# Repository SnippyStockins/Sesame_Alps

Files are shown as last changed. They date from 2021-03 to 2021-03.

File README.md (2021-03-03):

# Sesame

[][cc-by-nc-sa]

### Alice like ergo keyboard using only THT parts



### Partslist
 |Count|Part|
 |-|-|
 |1|ATmega32A 40 pin DIP (32L works too)|
 |1|40 pin DIP socket (optional but highly recommended)|
 |1|USB4085-GF-A USB Type-C socket|
 |1|500 mA polyfuse|
 |2|6mm momentary push buttons|
 |1|16 MHz quartz crystal|
 |1|4.7 uF electrolytic capacitor|
 |2|100 nF ceramic disk capacitor|
 |2|22 pF ceramic disk capacitor|
 |1|10 kΩ resistor|
 |2|68 Ω resistor|
 |1|1.5 kΩ resistor|
 |2|5.1 kΩ resistor|
 |2|3.6 V zener diode (DO-35 BZX55C3V6)|
 |66|universal switching diode (DO-35 1N4148)|




This work is licensed under a
[Creative Commons Attribution-NonCommercial-ShareAlike 4.0 International License][cc-by-nc-sa].

[][cc-by-nc-sa]

[cc-by-nc-sa]: http://creativecommons.org/licenses/by-nc-sa/4.0/
[cc-by-nc-sa-image]: https://licensebuttons.net/l/by-nc-sa/4.0/88x31.png
[cc-by-nc-sa-shield]: https://img.shields.io/badge/License-CC%20BY--NC--SA%204.0-lightgrey.svg

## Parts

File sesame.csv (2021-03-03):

Id | Designator | Package | Quantity | Designation | Supplier and ref
1 | MX69,MX8,MX1,MX47,MX23,MX5,MX24,MX28,MX16,MX32,MX68,MX59,MX58,MX57,MX56,MX55,MX54,MX53,MX52,MX51,MX50,MX49,MX45,MX44,MX43,MX42,MX41,MX40,MX39,MX38,MX37,MX36,MX35,MX33,MX30,MX29,MX27,MX26,MX25,MX22,MX21,MX20,MX19,MX17,MX14,MX13,MX12,MX11,MX10,MX9,MX7,MX6,MX4,MX3,MX2,MX70,MX61 | MX-1U-NoLED | 57 | MX-NoLED
2 | U1 | DIP-40_W15.24mm | 1 | ATmega32A-PU
3 | MX60,MX34 | MX-1.75U-NoLED | 2 | MX-NoLED
4 | USB1 | USB_C_Receptacle_GCT_USB4085 | 1 | USB_C_Receptacle_USB2.0
5 | R6 | R_Axial_DIN0204_L3.6mm_D1.6mm_P7.62mm_Horizontal | 1 | 10k
6 | R4,R5 | R_Axial_DIN0204_L3.6mm_D1.6mm_P7.62mm_Horizontal | 2 | 75R
7 | R3,R2 | R_Axial_DIN0204_L3.6mm_D1.6mm_P7.62mm_Horizontal | 2 | 5.1K
8 | R1 | R_Axial_DIN0204_L3.6mm_D1.6mm_P7.62mm_Horizontal | 1 | 1.5K
9 | C5,C4 | C_Disc_D3.0mm_W1.6mm_P2.50mm | 2 | 22p
10 | C3,C2 | C_Disc_D4.3mm_W1.9mm_P5.00mm | 2 | 0.1u
11 | MX18,MX31 | MX-1.5U-NoLED | 2 | MX-NoLED
12 | MX15 | MX-2U-NoLED | 1 | MX-NoLED
13 | MX46,MX48 | MX-2.25U-NoLED | 2 | MX-NoLED
14 | MX62,MX63,MX65,MX67 | MX-1.25U-NoLED | 4 | MX-NoLED
15 | MX64 | MX-2U-ReversedStabilizers-NoLED | 1 | MX-NoLED
16 | MX66 | MX-2.75U-ReversedStabilizers-NoLED | 1 | MX-NoLED
17 | C1 | CP_Radial_D4.0mm_P1.50mm | 1 | 4.7u
18 | REF**,REF**,REF**,REF**,REF**,REF**,REF** | screw_hole | 7 | screw_hole
19 | AVR1 | PinHeader_1x06_P2.54mm_Vertical | 1 | Conn_01x06
20 | D60,D68,D67,D66,D65,D64,D63,D62,D61,D59,D58,D57,D56,D55,D54,D53,D52,D51,D50,D49,D48,D47,D45,D44,D43,D42,D41,D40,D39,D38,D37,D36,D35,D34,D33,D32,D31,D30,D29,D28,D27,D26,D25,D24,D23,D22,D21,D20,D19,D18,D15,D46,D14,D13,D12,D11,D10,D9,D8,D7,D6,D5,D4,D3,D2,D1,D16,D17,D69,D70 | D_DO-35_SOD27_P7.62mm_Horizontal | 70 | D_Small
21 | XTAL1 | Crystal_HC49-4H_Vertical | 1 | Crystal
22 | Reset1 | SW_PUSH_6mm | 1 | Reset
23 | F1 | Fuse_Littelfuse_395Series | 1 | 500mA
24 | Boot1 | SW_PUSH_6mm | 1 | Boot
25 | D71,D72 | D_DO-35_SOD27_P7.62mm_Horizontal | 2 | 3.6V

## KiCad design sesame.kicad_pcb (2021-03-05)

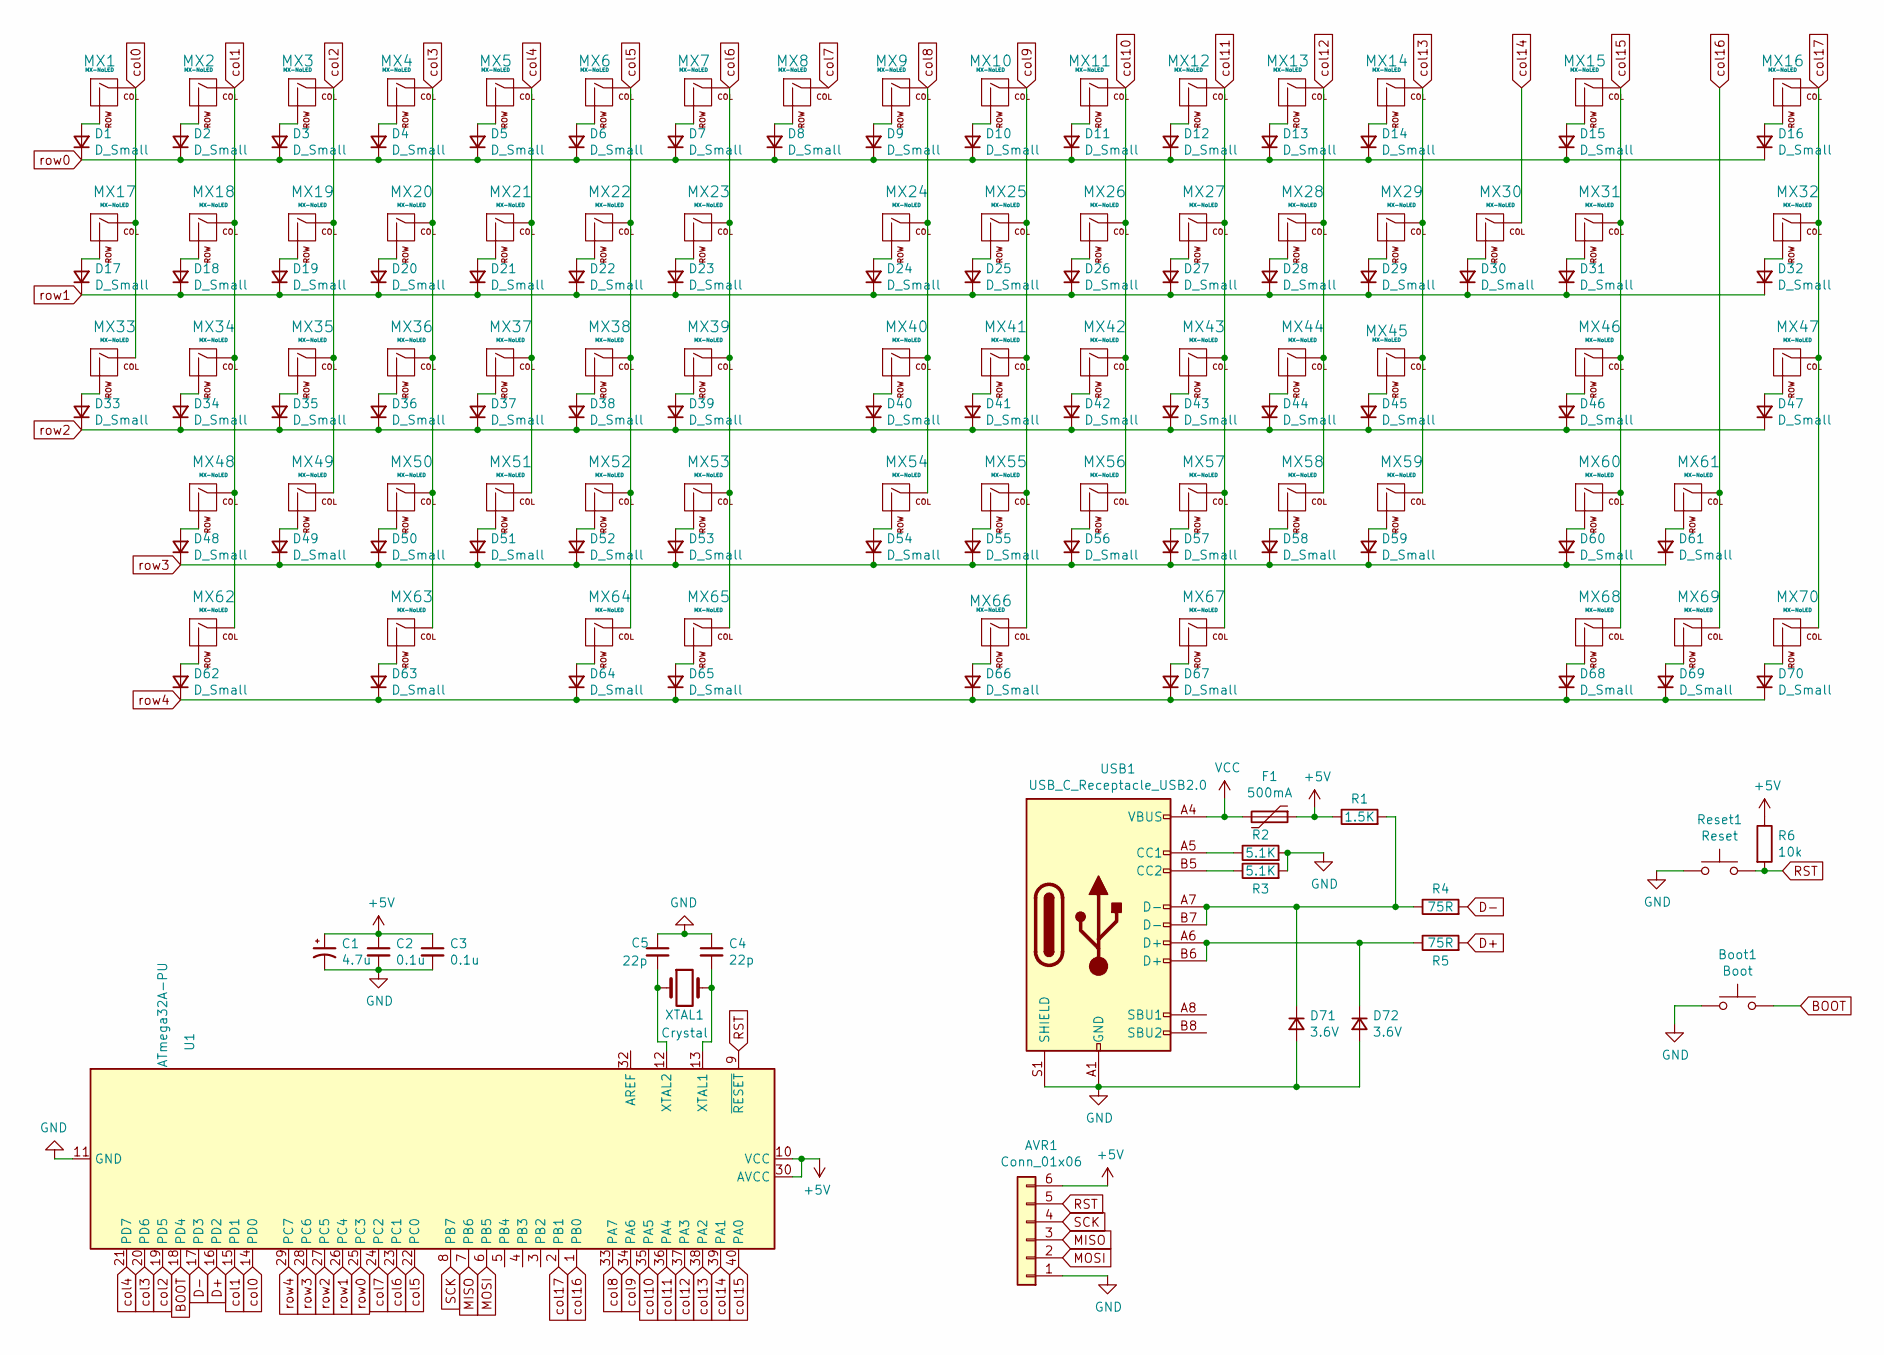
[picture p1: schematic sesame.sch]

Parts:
AVR1: Conn_01x06; PinHeader_1x06_P2.54mm_Vertical
Boot1: Boot; SW_PUSH_6mm
C1: 4.7u; CP_Radial_D4.0mm_P1.50mm
C2, C3: 0.1u; C_Disc_D4.3mm_W1.9mm_P5.00mm
C4, C5: 22p; C_Disc_D3.0mm_W1.6mm_P2.50mm
D1, D2, D3, D4, D5, D6, D7, D8, D9, D10, D11, D12, D13, D14, D15, D16, D17, D18, D19, D20, D21, D22, D23, D24, D25, D26, D27, D28, D29, D30, D31, D32, D33, D34, D35, D36, D37, D38, D39, D40, D41, D42, D43, D44, D45, D46, D47, D48, D49, D50, D51, D52, D53, D54, D55, D56, D57, D58, D59, D60, D61, D62, D63, D64, D65, D66, D67, D68, D69, D70: D_Small; D_DO-35_SOD27_P7.62mm_Horizontal
D71, D72: 3.6V; D_DO-35_SOD27_P7.62mm_Horizontal
F1: 500mA; Fuse_Littelfuse_395Series
MX1, MX2, MX3, MX4, MX5, MX6, MX7, MX8, MX9, MX10, MX11, MX12, MX13, MX14, MX16, MX17, MX19, MX20, MX21, MX22, MX23, MX24, MX25, MX26, MX27, MX28, MX29, MX30, MX32, MX33, MX35, MX36, MX37, MX38, MX39, MX40, MX41, MX42, MX43, MX44, MX45, MX47, MX49, MX50, MX51, MX52, MX53, MX54, MX55, MX56, MX57, MX58, MX59, MX61, MX68, MX69, MX70: MX-NoLED; MX-1U-NoLED
MX15: MX-NoLED; MX-2U-NoLED
MX18, MX31: MX-NoLED; MX-1.5U-NoLED
MX34, MX60: MX-NoLED; MX-1.75U-NoLED
MX46, MX48: MX-NoLED; MX-2.25U-NoLED
MX62, MX63, MX65, MX67: MX-NoLED; MX-1.25U-NoLED
MX64: MX-NoLED; MX-2U-ReversedStabilizers-NoLED
MX66: MX-NoLED; MX-2.75U-ReversedStabilizers-NoLED
R1: 1.5K; R_Axial_DIN0204_L3.6mm_D1.6mm_P7.62mm_Horizontal
R2, R3: 5.1K; R_Axial_DIN0204_L3.6mm_D1.6mm_P7.62mm_Horizontal
R4, R5: 75R; R_Axial_DIN0204_L3.6mm_D1.6mm_P7.62mm_Horizontal
R6: 10k; R_Axial_DIN0204_L3.6mm_D1.6mm_P7.62mm_Horizontal
Reset1: Reset; SW_PUSH_6mm
U1: ATmega32A-PU; DIP-40_W15.24mm
USB1: USB_C_Receptacle_USB2.0; USB_C_Receptacle_GCT_USB4085
XTAL1: Crystal; Crystal_HC49-4H_Vertical

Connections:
+5V: AVR1.6, C1.1, C2.1, C3.1, F1.1, R1.1, R6.1, U1.10 (VCC), U1.30 (AVCC)
BOOT: Boot1.2, U1.18 (PD4)
D+: R5.2, U1.16 (PD2)
D-: R4.2, U1.17 (PD3)
GND: AVR1.1, Boot1.1, C1.2, C2.2, C3.2, C4.1, C5.1, D71.2 (A), D72.2 (A), R2.2, R3.2, Reset1.1, U1.11 (GND), U1.31 (GND), USB1.A1 (GND), USB1.A12 (GND), USB1.B1 (GND), USB1.B12 (GND), USB1.S1 (SHIELD)
MISO: AVR1.3, U1.7 (PB6)
MOSI: AVR1.2, U1.6 (PB5)
unnamed: C4.2, U1.13 (XTAL1), XTAL1.2
unnamed: C5.2, U1.12 (XTAL2), XTAL1.1
unnamed: D1.2 (A), MX1.2 (ROW)
unnamed: D2.2 (A), MX2.2 (ROW)
unnamed: D3.2 (A), MX3.2 (ROW)
unnamed: D4.2 (A), MX4.2 (ROW)
unnamed: D5.2 (A), MX5.2 (ROW)
unnamed: D6.2 (A), MX6.2 (ROW)
unnamed: D7.2 (A), MX7.2 (ROW)
unnamed: D8.2 (A), MX8.2 (ROW)
unnamed: D9.2 (A), MX9.2 (ROW)
unnamed: D10.2 (A), MX10.2 (ROW)
unnamed: D11.2 (A), MX11.2 (ROW)
unnamed: D12.2 (A), MX12.2 (ROW)
unnamed: D13.2 (A), MX13.2 (ROW)
unnamed: D14.2 (A), MX14.2 (ROW)
unnamed: D15.2 (A), MX15.2 (ROW)
unnamed: D16.2 (A), MX16.2 (ROW)
unnamed: D17.2 (A), MX17.2 (ROW)
unnamed: D18.2 (A), MX18.2 (ROW)
unnamed: D19.2 (A), MX19.2 (ROW)
unnamed: D20.2 (A), MX20.2 (ROW)
unnamed: D21.2 (A), MX21.2 (ROW)
unnamed: D22.2 (A), MX22.2 (ROW)
unnamed: D23.2 (A), MX23.2 (ROW)
unnamed: D24.2 (A), MX24.2 (ROW)
unnamed: D25.2 (A), MX25.2 (ROW)
unnamed: D26.2 (A), MX26.2 (ROW)
unnamed: D27.2 (A), MX27.2 (ROW)
unnamed: D28.2 (A), MX28.2 (ROW)
unnamed: D29.2 (A), MX29.2 (ROW)
unnamed: D30.2 (A), MX30.2 (ROW)
unnamed: D31.2 (A), MX31.2 (ROW)
unnamed: D32.2 (A), MX32.2 (ROW)
unnamed: D33.2 (A), MX33.2 (ROW)
unnamed: D34.2 (A), MX34.2 (ROW)
unnamed: D35.2 (A), MX35.2 (ROW)
unnamed: D36.2 (A), MX36.2 (ROW)
unnamed: D37.2 (A), MX37.2 (ROW)
unnamed: D38.2 (A), MX38.2 (ROW)
unnamed: D39.2 (A), MX39.2 (ROW)
unnamed: D40.2 (A), MX40.2 (ROW)
unnamed: D41.2 (A), MX41.2 (ROW)
unnamed: D42.2 (A), MX42.2 (ROW)
unnamed: D43.2 (A), MX43.2 (ROW)
unnamed: D44.2 (A), MX44.2 (ROW)
unnamed: D45.2 (A), MX45.2 (ROW)
unnamed: D46.2 (A), MX46.2 (ROW)
unnamed: D47.2 (A), MX47.2 (ROW)
unnamed: D48.2 (A), MX48.2 (ROW)
unnamed: D49.2 (A), MX49.2 (ROW)
unnamed: D50.2 (A), MX50.2 (ROW)
unnamed: D51.2 (A), MX51.2 (ROW)
unnamed: D52.2 (A), MX52.2 (ROW)
unnamed: D53.2 (A), MX53.2 (ROW)
unnamed: D54.2 (A), MX54.2 (ROW)
unnamed: D55.2 (A), MX55.2 (ROW)
unnamed: D56.2 (A), MX56.2 (ROW)
unnamed: D57.2 (A), MX57.2 (ROW)
unnamed: D58.2 (A), MX58.2 (ROW)
unnamed: D59.2 (A), MX59.2 (ROW)
unnamed: D60.2 (A), MX60.2 (ROW)
unnamed: D61.2 (A), MX61.2 (ROW)
unnamed: D62.2 (A), MX62.2 (ROW)
unnamed: D63.2 (A), MX63.2 (ROW)
unnamed: D64.2 (A), MX64.2 (ROW)
unnamed: D65.2 (A), MX65.2 (ROW)
unnamed: D66.2 (A), MX66.2 (ROW)
unnamed: D67.2 (A), MX67.2 (ROW)
unnamed: D68.2 (A), MX68.2 (ROW)
unnamed: D69.2 (A), MX69.2 (ROW)
unnamed: D70.2 (A), MX70.2 (ROW)
unnamed: D71.1 (K), R1.2, R4.1, USB1.A7 (D-), USB1.B7 (D-)
unnamed: D72.1 (K), R5.1, USB1.A6 (D+), USB1.B6 (D+)
unnamed: R2.1, USB1.A5 (CC1)
unnamed: R3.1, USB1.B5 (CC2)
RST: AVR1.5, R6.2, Reset1.2, U1.9 (~RESET)
SCK: AVR1.4, U1.8 (PB7)
VCC: F1.2, USB1.A4 (VBUS), USB1.A9 (VBUS), USB1.B4 (VBUS), USB1.B9 (VBUS)
col0: MX1.1 (COL), MX17.1 (COL), MX33.1 (COL), U1.14 (PD0)
col1: MX2.1 (COL), MX18.1 (COL), MX34.1 (COL), MX48.1 (COL), MX62.1 (COL), U1.15 (PD1)
col2: MX3.1 (COL), MX19.1 (COL), MX35.1 (COL), MX49.1 (COL), U1.19 (PD5)
col3: MX4.1 (COL), MX20.1 (COL), MX36.1 (COL), MX50.1 (COL), MX63.1 (COL), U1.20 (PD6)
col4: MX5.1 (COL), MX21.1 (COL), MX37.1 (COL), MX51.1 (COL), U1.21 (PD7)
col5: MX6.1 (COL), MX22.1 (COL), MX38.1 (COL), MX52.1 (COL), MX64.1 (COL), U1.22 (PC0)
col6: MX7.1 (COL), MX23.1 (COL), MX39.1 (COL), MX53.1 (COL), MX65.1 (COL), U1.23 (PC1)
col7: MX8.1 (COL), U1.24 (PC2)
col8: MX9.1 (COL), MX24.1 (COL), MX40.1 (COL), MX54.1 (COL), U1.33 (PA7)
col9: MX10.1 (COL), MX25.1 (COL), MX41.1 (COL), MX55.1 (COL), MX66.1 (COL), U1.34 (PA6)
col10: MX11.1 (COL), MX26.1 (COL), MX42.1 (COL), MX56.1 (COL), U1.35 (PA5)
col11: MX12.1 (COL), MX27.1 (COL), MX43.1 (COL), MX57.1 (COL), MX67.1 (COL), U1.36 (PA4)
col12: MX13.1 (COL), MX28.1 (COL), MX44.1 (COL), MX58.1 (COL), U1.37 (PA3)
col13: MX14.1 (COL), MX29.1 (COL), MX45.1 (COL), MX59.1 (COL), U1.38 (PA2)
col14: MX30.1 (COL), U1.39 (PA1)
col15: MX15.1 (COL), MX31.1 (COL), MX46.1 (COL), MX60.1 (COL), MX68.1 (COL), U1.40 (PA0)
col16: MX61.1 (COL), MX69.1 (COL), U1.1 (PB0)
col17: MX16.1 (COL), MX32.1 (COL), MX47.1 (COL), MX70.1 (COL), U1.2 (PB1)
row0: D1.1 (K), D2.1 (K), D3.1 (K), D4.1 (K), D5.1 (K), D6.1 (K), D7.1 (K), D8.1 (K), D9.1 (K), D10.1 (K), D11.1 (K), D12.1 (K), D13.1 (K), D14.1 (K), D15.1 (K), D16.1 (K), U1.25 (PC3)
row1: D17.1 (K), D18.1 (K), D19.1 (K), D20.1 (K), D21.1 (K), D22.1 (K), D23.1 (K), D24.1 (K), D25.1 (K), D26.1 (K), D27.1 (K), D28.1 (K), D29.1 (K), D30.1 (K), D31.1 (K), D32.1 (K), U1.26 (PC4)
row2: D33.1 (K), D34.1 (K), D35.1 (K), D36.1 (K), D37.1 (K), D38.1 (K), D39.1 (K), D40.1 (K), D41.1 (K), D42.1 (K), D43.1 (K), D44.1 (K), D45.1 (K), D46.1 (K), D47.1 (K), U1.27 (PC5)
row3: D48.1 (K), D49.1 (K), D50.1 (K), D51.1 (K), D52.1 (K), D53.1 (K), D54.1 (K), D55.1 (K), D56.1 (K), D57.1 (K), D58.1 (K), D59.1 (K), D60.1 (K), D61.1 (K), U1.28 (PC6)
row4: D62.1 (K), D63.1 (K), D64.1 (K), D65.1 (K), D66.1 (K), D67.1 (K), D68.1 (K), D69.1 (K), D70.1 (K), U1.29 (PC7)

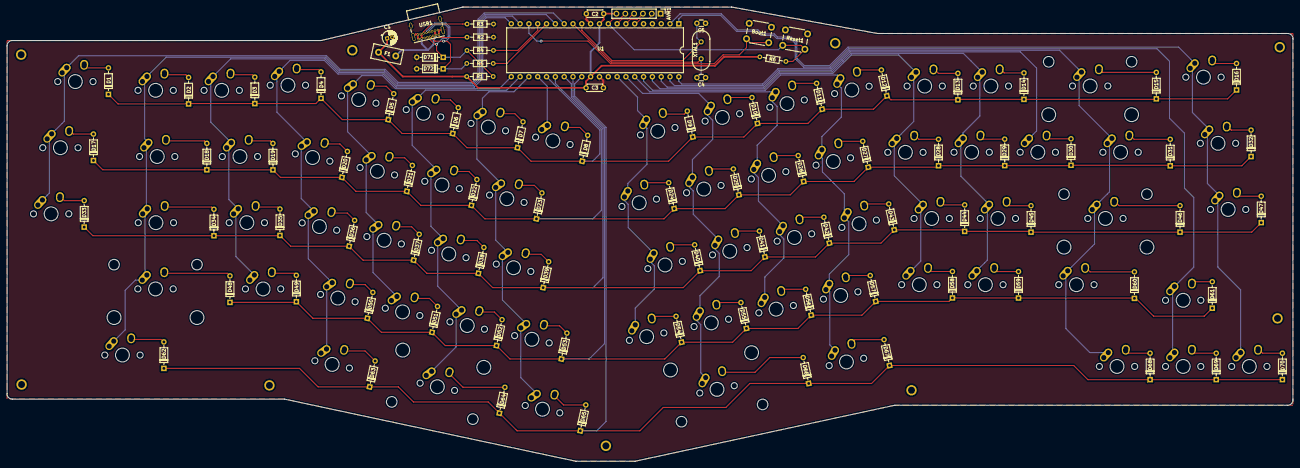
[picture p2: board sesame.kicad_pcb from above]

Board: 2 copper layers, 370.3 x 130.8 mm, 160 parts (0 on the bottom side), 109 nets.

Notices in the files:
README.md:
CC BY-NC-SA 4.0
